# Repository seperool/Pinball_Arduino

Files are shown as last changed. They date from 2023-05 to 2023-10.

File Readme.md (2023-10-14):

# 1 OBJETIVO

## 1.1 Projeto Pinball

Desenvolver um brinquedo simples para crianças com transtorno de especto
autista (TEA) que envolva circuitos elétricos.  
O projeto é um pinball, de dimensões portatil (um pouco maior que uma
caixa de sapatos), construido com *Arduino UNO R3*, seis *LEDs* e seis
sensores que mapeiam a movimentação da bola. Com base no mapeamento da
movimentação da bola, em pontos predeterminados, os pontos do jogo são
marcados e contados, ou a partida é reiniciada e os pontos são zerados.
Como pode ser observado um exemplo desse modelo de pinball na figura .  

<figure>
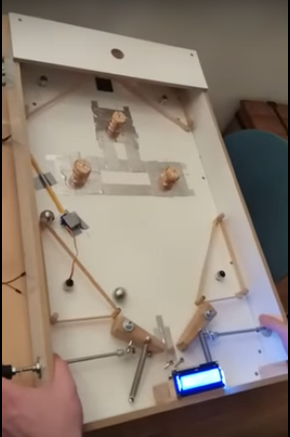
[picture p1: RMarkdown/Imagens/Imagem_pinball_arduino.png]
Exemplo pinball construido a partir de Arduino

<figcaption aria-hidden="true">Exemplo pinball construido a partir de
Arduino </figcaption>
</figure>

# 2 METODOLOGIA

## 2.1 Programação

    //Bibliotecas
    #include <LiquidCrystal.h>

    //Definindo os pinos que serão utilizados para ligação ao display LCD
    LiquidCrystal lcd(6, 7, 5, 4, 3, 2);

    //Definindo pinos dos LED
    int pinoLed_1 = 13; //Pino digital utilizado pelo LED 1 - Azul
    int pinoLed_2 = 12; //Pino digital utilizado pelo LED 2 - Verde
    int pinoLed_3 = 11; //Pino digital utilizado pelo LED 3 - Amarelo
    int pinoLed_4 = 10; //Pino digital utilizado pelo LED 4 - Vermelho
    int pinoLed_5 = 9; //Pino digital utilizado pelo LED 5 - Verde
    int pinoLed_6 = 8; //Pino digital utilizado pelo LED 6 - Azul

    // Cores LED e Pontos
    // Azul = LED 1 e 6 = 1 ponto
    // Verde = LED 2 e 5 = 2 ponto
    // Amarelo = LED 3 = 3 ponto
    // Vermelho = LED 4 = 0 ponto

    //Definindo pinos dos sensores óptico tcrt5000
    int pinoSensor_1 = 14; //Pino analogico A0 transformado em pino digital utilizado pelo sensor 1
    int pinoSensor_2 = 15; //Pino analogico A1 transformado em pino digital utilizado pelo sensor 2
    int pinoSensor_3 = 16; //Pino analogico A2 transformado em pino digital utilizado pelo sensor 3
    int pinoSensor_4 = 17; //Pino analogico A3 transformado em pino digital utilizado pelo sensor 4
    int pinoSensor_5 = 18; //Pino analogico A4 transformado em pino digital utilizado pelo sensor 5
    int pinoSensor_6 = 19; //Pino analogico A5 transformado em pino digital utilizado pelo sensor 6

    // Relação entre LED e sensores - Pinos
    // pinoSensor_1 -> pinoLed_1 - Pinos A0 e 13
    // pinoSensor_2 -> pinoLed_2 - Pinos A1 e 12
    // pinoSensor_3 -> pinoLed_3 - Pinos A2 e 11
    // pinoSensor_4 -> pinoLed_4 - Pinos A3 e 10
    // pinoSensor_5 -> pinoLed_5 - Pinos A4 e 9
    // pinoSensor_6 -> pinoLed_6 - Pinos A5 e 8

    // Variáveis
    int point = 0; //Contador de pontos
    int stop = 500; //Tempo de parada para o delay

    void setup() {
      //Define o número de colunas e linhas do LCD
      lcd.begin(16, 2);
      
      // Inicializando os Sensores
      pinMode(pinoSensor_1, INPUT); //Definindo o pino como entrada para o sensor 1
      pinMode(pinoSensor_2, INPUT); //Definindo o pino como entrada para o sensor 2
      pinMode(pinoSensor_3, INPUT); //Definindo o pino como entrada para o sensor 3
      pinMode(pinoSensor_4, INPUT); //Definindo o pino como entrada para o sensor 4
      pinMode(pinoSensor_5, INPUT); //Definindo o pino como entrada para o sensor 5
      pinMode(pinoSensor_6, INPUT); //Definindo o pino como entrada para o sensor 6

      // Inicializando os LED
      pinMode(pinoLed_1, OUTPUT); //Definindo o pino como saída para o LED 1 - Verde
      pinMode(pinoLed_2, OUTPUT); //Definindo o pino como saída para o LED 2 - Azul
      pinMode(pinoLed_3, OUTPUT); //Definindo o pino como saída para o LED 3 - Amarelo
      pinMode(pinoLed_4, OUTPUT); //Definindo o pino como saída para o LED 4 - Vermelho
      pinMode(pinoLed_5, OUTPUT); //Definindo o pino como saída para o LED 5 - Verde
      pinMode(pinoLed_6, OUTPUT); //Definindo o pino como saída para o LED 6 - Azul
      
      // Desligando os LED
      digitalWrite(pinoLed_1, LOW); //LED 1 inicia desligado
      digitalWrite(pinoLed_2, LOW); //LED 2 inicia desligado
      digitalWrite(pinoLed_3, LOW); //LED 3 inicia desligado
      digitalWrite(pinoLed_4, LOW); //LED 4 inicia desligado
      digitalWrite(pinoLed_5, LOW); //LED 5 inicia desligado
      digitalWrite(pinoLed_6, LOW); //LED 6 inicia desligado
    }

    void loop() {
      //Sensor
      if (digitalRead(pinoSensor_1) == LOW){ //Se a leitura do sensor 1 (Azul) for igual a LOW, faz
        digitalWrite(pinoLed_1, HIGH); //Acende o LED 1 - Azul
        point=point+1; //Adiciona 1 ponto
      }else if(digitalRead(pinoSensor_2) == LOW){ //Se a leitura do sensor 2 (Verde)) for igual a LOW, faz
        digitalWrite(pinoLed_2, HIGH); //Acende o LED 2 - Verde
        point=point+2; //Adiciona 2 ponto
      }else if(digitalRead(pinoSensor_3) == LOW){ //Se a leitura do sensor 3 (Amarelo) for igual a LOW, faz
        digitalWrite(pinoLed_3, HIGH); //Acende o LED 3 - Amarelo
        point=point+3; //Adiciona 3 ponto
      }else if(digitalRead(pinoSensor_5) == LOW){ //Se a leitura do sensor 5 (Verde) for igual a LOW, faz
        digitalWrite(pinoLed_5, HIGH); //Acende o LED 5 - Verde
        point=point+2; //Adiciona 2 ponto
      }else if(digitalRead(pinoSensor_6) == LOW){ //Se a leitura do sensor 6 (Azul) for igual a LOW, faz
        digitalWrite(pinoLed_6, HIGH); //Acende o LED 6 - Azul
        point=point+1; //Adiciona 1 ponto
      }else if(digitalRead(pinoSensor_4) == LOW){ //Se a leitura do sensor 4 (Vermelho) for igual a LOW, faz
        digitalWrite(pinoLed_4, HIGH); //Acende o LED 4 - Vermelho
        point=0; //Reinicia a contagem
      }
      
      //LCD
      //Limpa a tela
      lcd.clear();
      //Posiciona o cursor na coluna 1, linha 0;
      lcd.setCursor(1, 0);
      //Envia o texto entre aspas para o LCD
      lcd.print("Jogo Placar");
      //Posiciona o cursor na coluna 1, linha 1;
      lcd.setCursor(1, 1);
      //Imprime Contador de pontuação
      lcd.print(point);
      delay(stop);
      
      // Apagar LED
      digitalWrite(pinoLed_1, LOW); //Apaga o LED 1
      digitalWrite(pinoLed_2, LOW); //Apaga o LED 2
      digitalWrite(pinoLed_3, LOW); //Apaga o LED 3
      digitalWrite(pinoLed_4, LOW); //Apaga o LED 4
      digitalWrite(pinoLed_5, LOW); //Apaga o LED 5
      digitalWrite(pinoLed_6, LOW); //Apaga o LED 6
    }

## 2.2 Circuito

### 2.2.1 *Software* de desenho do circuito

Para os desenhos do circuito foi utilizado o software tipo *CAD*
[*Fritzing*](https://fritzing.org/), de codigo aberto, na versão beta. O
software oferece a possibilidade de desenhar tanto o modelo *breadboard*
quando o esquemático do circuito com arduino, sendo suas vantagens uma
biblioteca de dispositivos eletrônicos vasta, uma comunidade ativa para
tirar dúvidas e a criação de novos dispositivos eletrônicos.  

### 2.2.2 Breadboard

<figure>
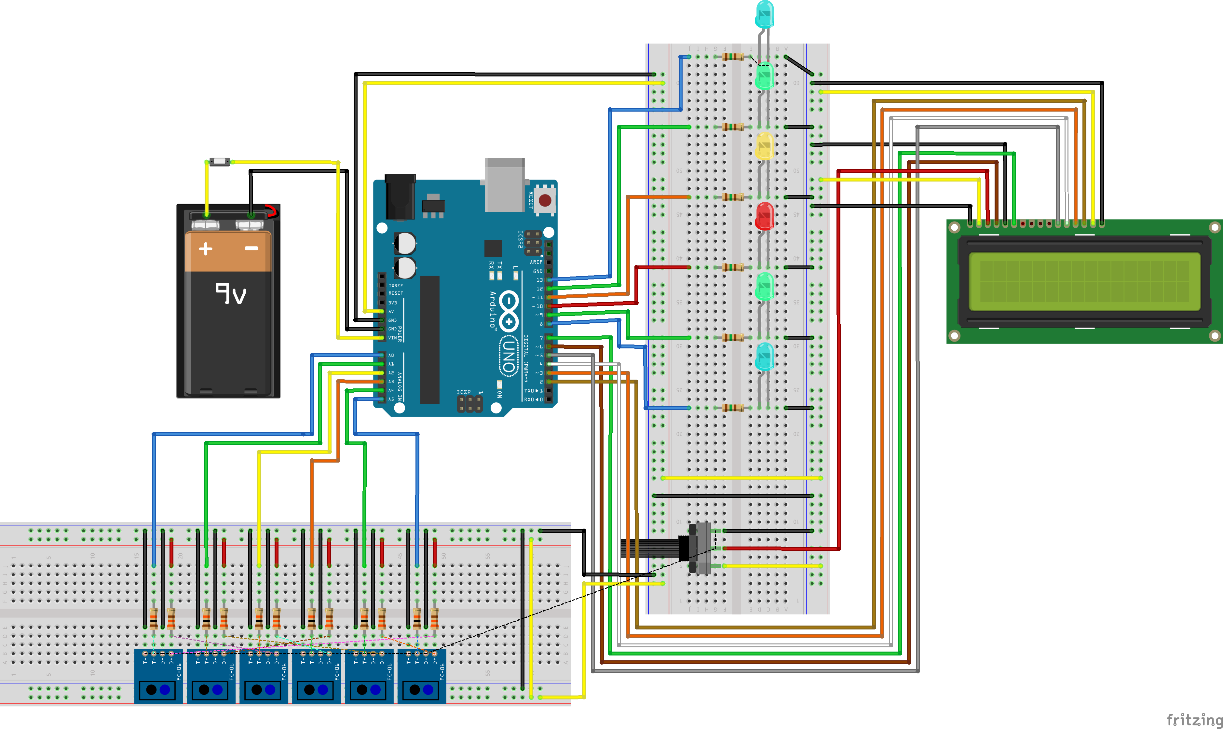
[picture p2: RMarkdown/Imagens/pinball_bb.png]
Circuito do Arduino com seis sensores ópticos, seis LEDs e um LCD.

<figcaption aria-hidden="true">Circuito do Arduino com seis sensores
ópticos, seis <em>LEDs</em> e um <em>LCD</em>. </figcaption>
</figure>

### 2.2.3 Diagrama esquemático

<figure>
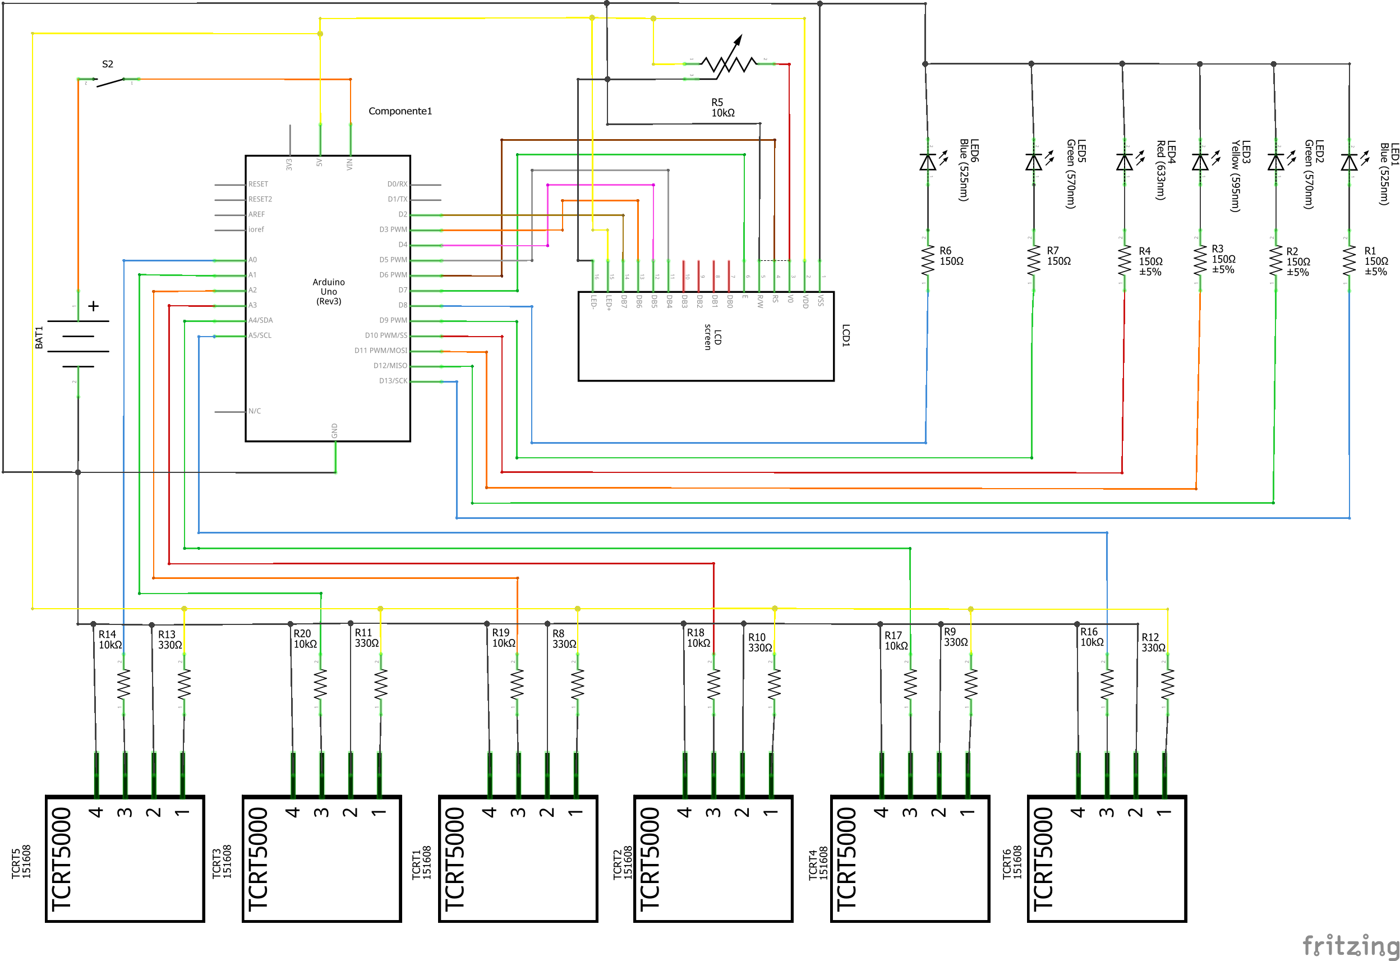
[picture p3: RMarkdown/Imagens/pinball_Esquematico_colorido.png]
Diagrama Esquemático do circuito do Arduino com seis sensores ópticos, seis LEDs e um LCD.

<figcaption aria-hidden="true">Diagrama Esquemático do circuito do
Arduino com seis sensores ópticos, seis <em>LEDs</em> e um
<em>LCD</em>.</figcaption>
</figure>

## 2.3 Modelagem estrutura

O desenho do Pinball foi desenvolvido com auxilio do *software*
[SolidWorks](https://www.solidworks.com/pt-br).  
O prototipo pode ser observado na figura .  

<figure>
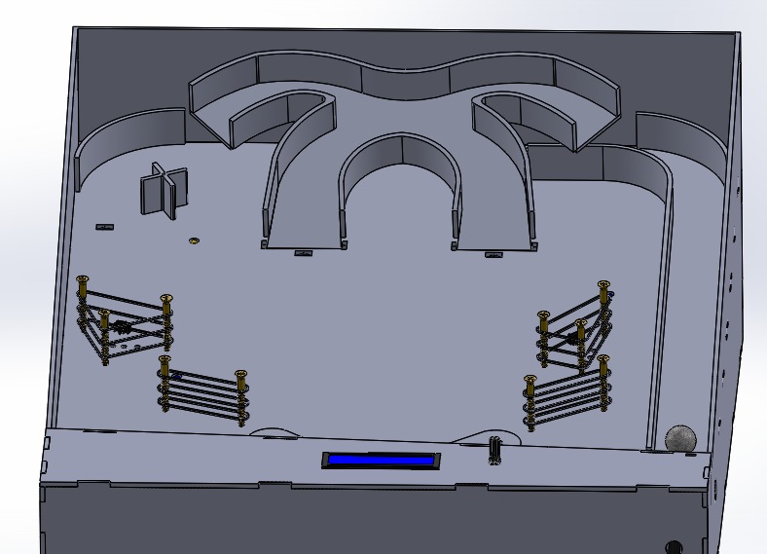
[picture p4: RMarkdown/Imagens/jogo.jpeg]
Pinball prototipo.

<figcaption aria-hidden="true">Pinball prototipo.</figcaption>
</figure>

Alguns detalhes como a rampa ficam evidenciadas na figura e o mecanismo
de lançamento da esfera na figura .  

<figure>
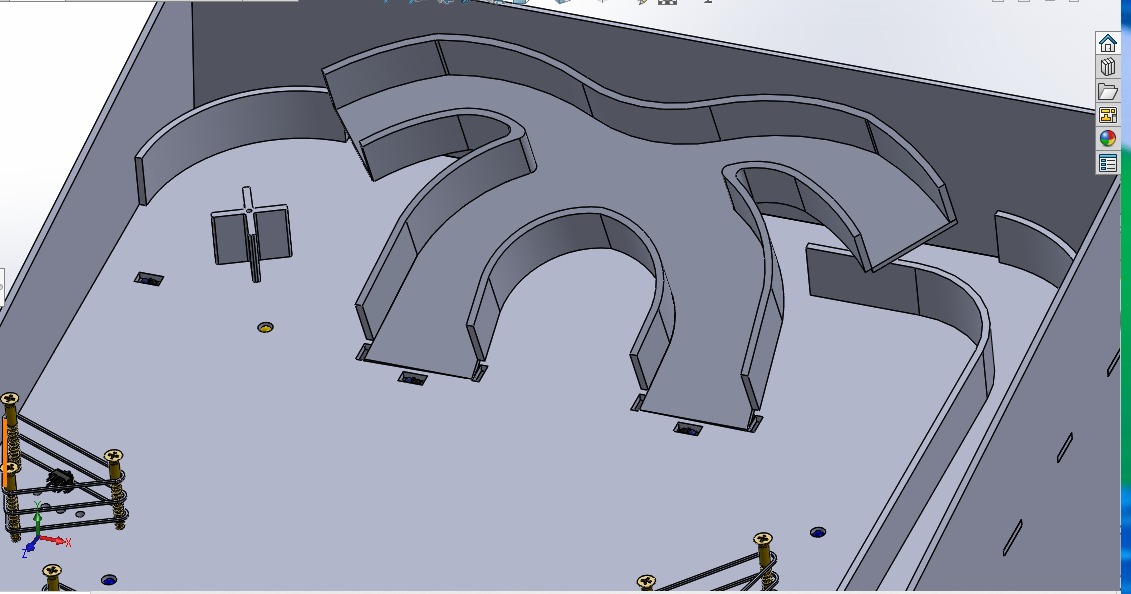
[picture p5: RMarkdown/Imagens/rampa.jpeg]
Detalhe da rampa.

<figcaption aria-hidden="true">Detalhe da rampa.</figcaption>
</figure>

<figure>
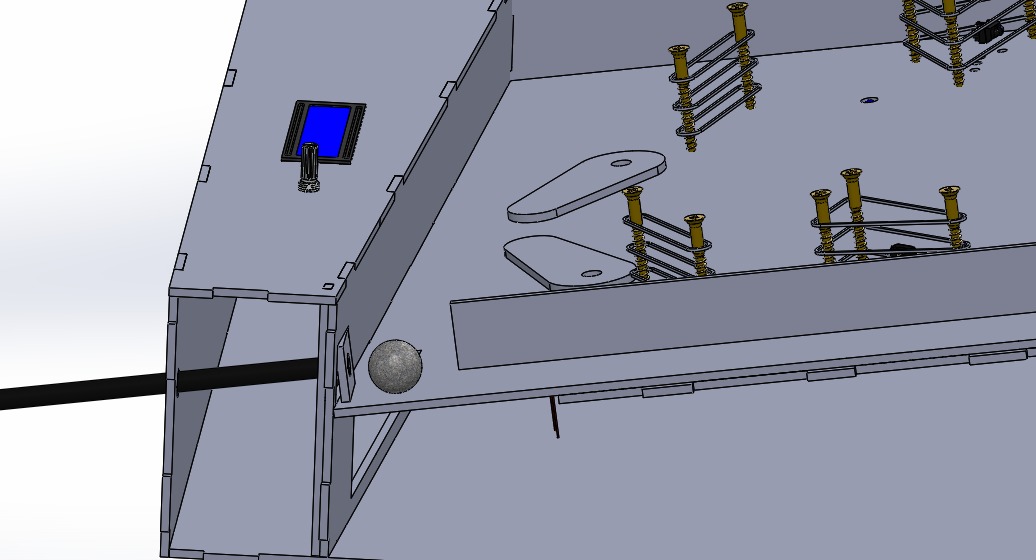
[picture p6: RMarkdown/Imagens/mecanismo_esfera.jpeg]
Mecanismo de lançamento da esfera.

<figcaption aria-hidden="true">Mecanismo de lançamento da
esfera.</figcaption>
</figure>

As vistas principais do Pinball nas figuras , e .  

<figure>
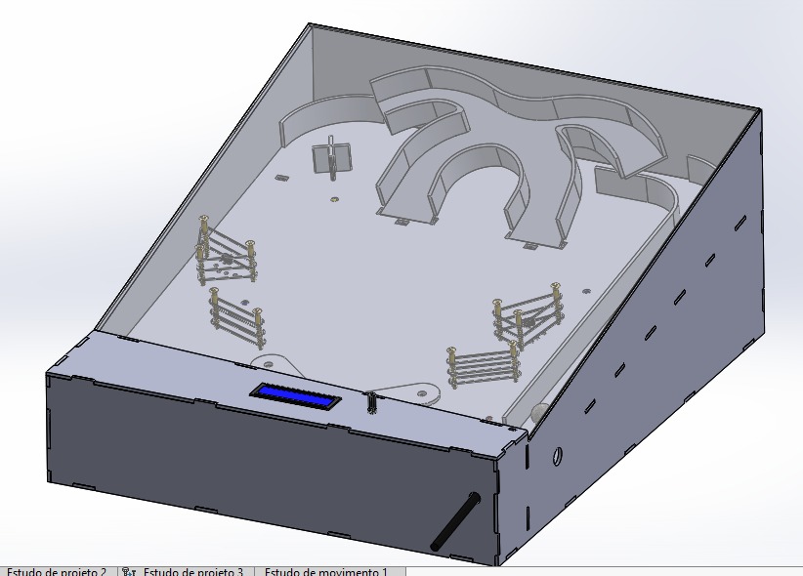
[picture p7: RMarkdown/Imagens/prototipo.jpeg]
Vista ortogonal.

<figcaption aria-hidden="true">Vista ortogonal.</figcaption>
</figure>

<figure>
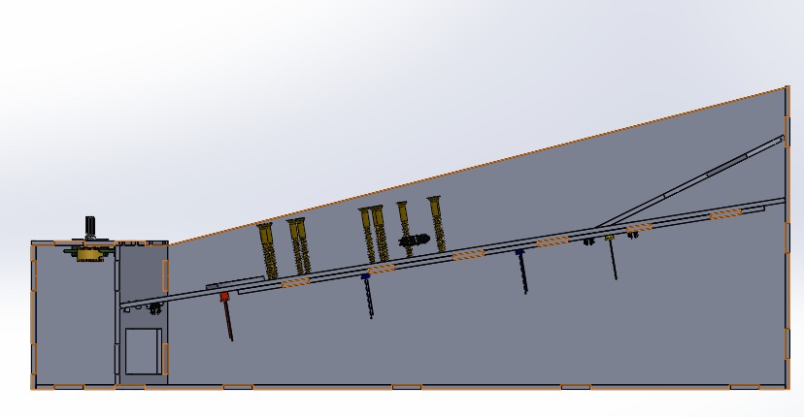
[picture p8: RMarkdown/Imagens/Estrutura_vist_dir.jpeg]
Vista da lateral direita.

<figcaption aria-hidden="true">Vista da lateral direita.</figcaption>
</figure>

<figure>
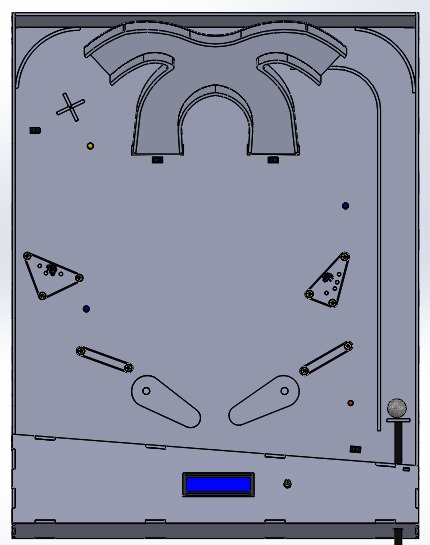
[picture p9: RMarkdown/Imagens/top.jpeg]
Vista superior.

<figcaption aria-hidden="true">Vista superior.</figcaption>
</figure>

## 2.4 Testes

Foram feitos dois testes do protótipo do circuito eletrônico:  
1. O primeiro para averiguar como seria o circuito na sua forma mais
simples, apenas o *Arduino UNO*, um sensor óptico, um *LED* e uma placa
de *LCD*, e a programação básica do Arduino para essa situação.  
Os principais fatores considerados foram:  
- A estrutura básica do circuito.  
- O funcionamento do *LCD*.  
- A programação básica implementada para unir esses componentes (sensor
óptico, *LED* e placa de *LCD*).  
2. O segundo experimento foi para ampliar o circuito, adicionando mais
cinco sensores ópticos e mais cinco *LEDs* (Figura ):  
- Averiguar a programação (como observada no Apêndice A).  
- Definir os pinos de cada componente eletrônico em relação ao *Arduino
UNO*.  
- A disposição e o sistema de cores definido para os *LEDs*,
relacionando os sensores e *LEDs*.  
- Transformação de pinos analógicos para digitais no *Arduino*, através
de programação, para comportar todos os componentes.  
- Testar da estrutura condicional (*if-else*) da programação.  
- O tempo ideal de *delay* para reconhecimento do objeto (bola de gude)
pelos sensores.  
- Definir e testar o sistema de pontuação do jogo.

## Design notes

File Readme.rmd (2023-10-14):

---
title: "Projeto Pinball"
subtitle: "Circuitos Elétricos 2"
author:
  - Franciellen Thurler Freire Allemão
  - Maria Clara Gonçalves de Almeida
  - Sergio Pedro Rodrigues Oliveira
date: "`r format(Sys.time(), '%d %B %Y')`"
committee:
  name: Paulo Victor de Souza Borges
  position: Orientador acadêmico
##lof: true
##lot: true
##toc-title: SUMÁRIO
output:
  md_document:
    number_sections: true
    variant: markdown_github
  pdf_document: 
    number_sections: true
    toc: FALSE
header-includes:
  - \usepackage{titling}
  - \pretitle{\begin{center}
    \includegraphics{./RMarkdown/azul.png}\LARGE\\}
  - \posttitle{\end{center}}
  - \renewcommand{\and}{\\}
bibliography: RMarkdown/Bibliografia_arduino.bib
csl: RMarkdown/abnt.csl
---

\thispagestyle{empty}

\newpage

\pagenumbering{roman}

```{=latex}
\setcounter{tocdepth}{4}
\renewcommand{\contentsname}{SUMÁRIO}
\tableofcontents
```

\newpage

```{=latex}
\setcounter{tocdepth}{4}
\renewcommand{\listfigurename}{LISTA DE FIGURAS}
\listoffigures
```

\newpage

```{=latex}
\setcounter{tocdepth}{4}
\renewcommand{\listtablename}{LISTA DE TABELAS}
\listoftables
```

```{r Pacotes, echo=FALSE, message=FALSE, warning=FALSE}
library(knitr)
```

\newpage

# OBJETIVO
## Projeto Pinball

Desenvolver um brinquedo simples para crianças com transtorno de especto autista (TEA) que envolva circuitos elétricos.\
O projeto é um pinball, de dimensões portatil (um pouco maior que uma caixa de sapatos), construido com *Arduino UNO R3*, seis *LEDs* e seis sensores que mapeiam a movimentação da bola. Com base no mapeamento da movimentação da bola, em pontos predeterminados, os pontos do jogo são marcados e contados, ou a partida é reiniciada e os pontos são zerados. Como pode ser observado um exemplo desse modelo de pinball na figura \ref{pinball_ex}.\

Exemplo pinball construido a partir de Arduino \label{pinball_ex}

\pagenumbering{arabic}
\newpage

# METODOLOGIA

## Programação

```
//Bibliotecas
#include <LiquidCrystal.h>

//Definindo os pinos que serão utilizados para ligação ao display LCD
LiquidCrystal lcd(6, 7, 5, 4, 3, 2);

//Definindo pinos dos LED
int pinoLed_1 = 13; //Pino digital utilizado pelo LED 1 - Azul
int pinoLed_2 = 12; //Pino digital utilizado pelo LED 2 - Verde
int pinoLed_3 = 11; //Pino digital utilizado pelo LED 3 - Amarelo
int pinoLed_4 = 10; //Pino digital utilizado pelo LED 4 - Vermelho
int pinoLed_5 = 9; //Pino digital utilizado pelo LED 5 - Verde
int pinoLed_6 = 8; //Pino digital utilizado pelo LED 6 - Azul

// Cores LED e Pontos
// Azul = LED 1 e 6 = 1 ponto
// Verde = LED 2 e 5 = 2 ponto
// Amarelo = LED 3 = 3 ponto
// Vermelho = LED 4 = 0 ponto

//Definindo pinos dos sensores óptico tcrt5000
int pinoSensor_1 = 14; //Pino analogico A0 transformado em pino digital utilizado pelo sensor 1
int pinoSensor_2 = 15; //Pino analogico A1 transformado em pino digital utilizado pelo sensor 2
int pinoSensor_3 = 16; //Pino analogico A2 transformado em pino digital utilizado pelo sensor 3
int pinoSensor_4 = 17; //Pino analogico A3 transformado em pino digital utilizado pelo sensor 4
int pinoSensor_5 = 18; //Pino analogico A4 transformado em pino digital utilizado pelo sensor 5
int pinoSensor_6 = 19; //Pino analogico A5 transformado em pino digital utilizado pelo sensor 6

// Relação entre LED e sensores - Pinos
// pinoSensor_1 -> pinoLed_1 - Pinos A0 e 13
// pinoSensor_2 -> pinoLed_2 - Pinos A1 e 12
// pinoSensor_3 -> pinoLed_3 - Pinos A2 e 11
// pinoSensor_4 -> pinoLed_4 - Pinos A3 e 10
// pinoSensor_5 -> pinoLed_5 - Pinos A4 e 9
// pinoSensor_6 -> pinoLed_6 - Pinos A5 e 8

// Variáveis
int point = 0; //Contador de pontos
int stop = 500; //Tempo de parada para o delay

void setup() {
  //Define o número de colunas e linhas do LCD
  lcd.begin(16, 2);
  
  // Inicializando os Sensores
  pinMode(pinoSensor_1, INPUT); //Definindo o pino como entrada para o sensor 1
  pinMode(pinoSensor_2, INPUT); //Definindo o pino como entrada para o sensor 2
  pinMode(pinoSensor_3, INPUT); //Definindo o pino como entrada para o sensor 3
  pinMode(pinoSensor_4, INPUT); //Definindo o pino como entrada para o sensor 4
  pinMode(pinoSensor_5, INPUT); //Definindo o pino como entrada para o sensor 5
  pinMode(pinoSensor_6, INPUT); //Definindo o pino como entrada para o sensor 6

  // Inicializando os LED
  pinMode(pinoLed_1, OUTPUT); //Definindo o pino como saída para o LED 1 - Verde
  pinMode(pinoLed_2, OUTPUT); //Definindo o pino como saída para o LED 2 - Azul
  pinMode(pinoLed_3, OUTPUT); //Definindo o pino como saída para o LED 3 - Amarelo
  pinMode(pinoLed_4, OUTPUT); //Definindo o pino como saída para o LED 4 - Vermelho
  pinMode(pinoLed_5, OUTPUT); //Definindo o pino como saída para o LED 5 - Verde
  pinMode(pinoLed_6, OUTPUT); //Definindo o pino como saída para o LED 6 - Azul
  
  // Desligando os LED
  digitalWrite(pinoLed_1, LOW); //LED 1 inicia desligado
  digitalWrite(pinoLed_2, LOW); //LED 2 inicia desligado
  digitalWrite(pinoLed_3, LOW); //LED 3 inicia desligado
  digitalWrite(pinoLed_4, LOW); //LED 4 inicia desligado
  digitalWrite(pinoLed_5, LOW); //LED 5 inicia desligado
  digitalWrite(pinoLed_6, LOW); //LED 6 inicia desligado
}

void loop() {
  //Sensor
  if (digitalRead(pinoSensor_1) == LOW){ //Se a leitura do sensor 1 (Azul) for igual a LOW, faz
    digitalWrite(pinoLed_1, HIGH); //Acende o LED 1 - Azul
    point=point+1; //Adiciona 1 ponto
  }else if(digitalRead(pinoSensor_2) == LOW){ //Se a leitura do sensor 2 (Verde)) for igual a LOW, faz
	digitalWrite(pinoLed_2, HIGH); //Acende o LED 2 - Verde
    point=point+2; //Adiciona 2 ponto
  }else if(digitalRead(pinoSensor_3) == LOW){ //Se a leitura do sensor 3 (Amarelo) for igual a LOW, faz
	digitalWrite(pinoLed_3, HIGH); //Acende o LED 3 - Amarelo
    point=point+3; //Adiciona 3 ponto
  }else if(digitalRead(pinoSensor_5) == LOW){ //Se a leitura do sensor 5 (Verde) for igual a LOW, faz
    digitalWrite(pinoLed_5, HIGH); //Acende o LED 5 - Verde
    point=point+2; //Adiciona 2 ponto
  }else if(digitalRead(pinoSensor_6) == LOW){ //Se a leitura do sensor 6 (Azul) for igual a LOW, faz
    digitalWrite(pinoLed_6, HIGH); //Acende o LED 6 - Azul
    point=point+1; //Adiciona 1 ponto
  }else if(digitalRead(pinoSensor_4) == LOW){ //Se a leitura do sensor 4 (Vermelho) for igual a LOW, faz
	digitalWrite(pinoLed_4, HIGH); //Acende o LED 4 - Vermelho
    point=0; //Reinicia a contagem
  }
  
  //LCD
  //Limpa a tela
  lcd.clear();
  //Posiciona o cursor na coluna 1, linha 0;
  lcd.setCursor(1, 0);
  //Envia o texto entre aspas para o LCD
  lcd.print("Jogo Placar");
  //Posiciona o cursor na coluna 1, linha 1;
  lcd.setCursor(1, 1);
  //Imprime Contador de pontuação
  lcd.print(point);
  delay(stop);
  
  // Apagar LED
  digitalWrite(pinoLed_1, LOW); //Apaga o LED 1
  digitalWrite(pinoLed_2, LOW); //Apaga o LED 2
  digitalWrite(pinoLed_3, LOW); //Apaga o LED 3
  digitalWrite(pinoLed_4, LOW); //Apaga o LED 4
  digitalWrite(pinoLed_5, LOW); //Apaga o LED 5
  digitalWrite(pinoLed_6, LOW); //Apaga o LED 6
}
```

## Circuito

### *Software* de desenho do circuito

Para os desenhos do circuito foi utilizado o software tipo *CAD* [*Fritzing*](https://fritzing.org/), de codigo aberto, na versão beta. O software oferece a possibilidade de desenhar tanto o modelo *breadboard* quando o esquemático do circuito com arduino, sendo suas vantagens uma biblioteca de dispositivos eletrônicos vasta, uma comunidade ativa para tirar dúvidas e a criação de novos dispositivos eletrônicos.\

### Breadboard

Circuito do Arduino com seis sensores ópticos, seis *LEDs* e um *LCD*. \label{circuito_bb}

\newpage

### Diagrama esquemático

Diagrama Esquemático do circuito do Arduino com seis sensores ópticos, seis *LEDs* e um *LCD*.

\newpage

## Modelagem estrutura
O desenho do Pinball foi desenvolvido com auxilio do *software* [SolidWorks](https://www.solidworks.com/pt-br).\
O prototipo pode ser observado na figura \ref{prototipo}.\

Pinball prototipo.\label{prototipo}

Alguns detalhes como a rampa ficam evidenciadas na figura \ref{rampa} e o mecanismo de lançamento da esfera na figura \ref{mecanismo_lançamento}.\

Detalhe da rampa.\label{rampa}

Mecanismo de lançamento da esfera.\label{mecanismo_lançamento}

As vistas principais do Pinball nas figuras \ref{est_ort}, \ref{est_dir} e \ref{est_top}.\

Vista ortogonal.\label{est_ort}

Vista da lateral direita.\label{est_dir}

Vista superior.\label{est_top}

\newpage

## Testes

Foram feitos dois testes do protótipo do circuito eletrônico:\
1. O primeiro para averiguar como seria o circuito na sua forma mais simples, apenas o *Arduino UNO*, um sensor óptico, um *LED* e uma placa de *LCD*, e a programação básica do Arduino para essa situação.\
Os principais fatores considerados foram:\
- A estrutura básica do circuito.\
- O funcionamento do *LCD*.\
- A programação básica implementada para unir esses componentes (sensor óptico, *LED* e placa de *LCD*).\
2. O segundo experimento foi para ampliar o circuito, adicionando mais cinco sensores ópticos e mais cinco *LEDs* (Figura \ref{circuito_bb}):\
- Averiguar a programação (como observada no Apêndice A).\
- Definir os pinos de cada componente eletrônico em relação ao *Arduino UNO*.\
- A disposição e o sistema de cores definido para os *LEDs*, relacionando os sensores e *LEDs*.\
- Transformação de pinos analógicos para digitais no *Arduino*, através de programação, para comportar todos os componentes.\
- Testar da estrutura condicional (*if-else*) da programação.\
- O tempo ideal de *delay* para reconhecimento do objeto (bola de gude) pelos sensores.\
- Definir e testar o sistema de pontuação do jogo.\

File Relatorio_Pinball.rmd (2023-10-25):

---
title: "Projeto Pinball"
subtitle: "Circuitos Elétricos 2"
author:
  - Franciellen Thurler Freire Allemão
  - Maria Clara Gonçalves de Almeida
  - Sergio Pedro Rodrigues Oliveira
date: "`r format(Sys.time(), '%d %B %Y')`"
committee:
  name: Paulo Victor de Souza Borges
  position: Orientador acadêmico
##lof: true
##lot: true
##toc-title: SUMÁRIO
output:
  odt_document: 
    number_sections: true
  md_document:
    number_sections: true
    variant: markdown_github
  html_document:
    number_sections: true
    df_print: paged
  github_document: 
  pdf_document: 
    number_sections: true
    toc: FALSE
  word_document: 
    toc: TRUE
    number_sections: true
header-includes:
  - \usepackage{titling}
  - \pretitle{\begin{center}
    \includegraphics{./RMarkdown/azul.png}\LARGE\\}
  - \posttitle{\end{center}}
  - \renewcommand{\and}{\\}
bibliography: RMarkdown/Bibliografia_arduino.bib
csl: RMarkdown/abnt.csl
---

\thispagestyle{empty}

\newpage

\pagenumbering{roman}

```{=latex}
\setcounter{tocdepth}{4}
\renewcommand{\contentsname}{SUMÁRIO}
\tableofcontents
```

\newpage

```{=latex}
\setcounter{tocdepth}{4}
\renewcommand{\listfigurename}{LISTA DE FIGURAS}
\listoffigures
```

\newpage

```{=latex}
\setcounter{tocdepth}{4}
\renewcommand{\listtablename}{LISTA DE TABELAS}
\listoftables
```

```{r Pacotes, echo=FALSE, message=FALSE, warning=FALSE}
library(knitr)
```

\newpage

# OBJETIVO
## Projeto Pinball

Desenvolver um brinquedo simples para crianças com transtorno de especto autista (TEA) que envolva circuitos elétricos.\
O projeto é um pinball, de dimensões portatil (um pouco maior que uma caixa de sapatos), construido com *Arduino UNO R3*, seis *LEDs* e seis sensores que mapeiam a movimentação da bola. Com base no mapeamento da movimentação da bola, em pontos predeterminados, os pontos do jogo são marcados e contados, ou a partida é reiniciada e os pontos são zerados. Como pode ser observado um exemplo desse modelo de pinball na figura \ref{pinball_ex}.\

Exemplo pinball construido a partir de Arduino \label{pinball_ex}

\pagenumbering{arabic}
\newpage

# LISTA DE MATERIAIS

```{r Lista_materiais, echo=FALSE, message=FALSE, warning=FALSE}
#data.frame
materiais <- c("Arduino UNO R3",
                  "Case para Arduino UNO",
                  "LED Difuso 5mm Vermelho",
                  "LED Difuso 5mm Amarelo",
                  "LED Difuso 5mm Azul",
                  "LED Difuso 5mm Verde",
                  "Resistor de 330 Ohm",
                  "Resistor de 150 Ohm",
                  "Resistor de 10k Ohm",
                  "Potenciometro 10k",
                  "Display LCD 16×2 Backlight Verde",
                  "Sensor Óptico Reflexivo TCRT5000",
                  "Cabos Jumper macho-macho",
                  "Tubo Termo Retrátil",
                  "Protoboard",
                  "Suporte Bateria 9V Plug P4",
                  "Bateria Recarregável 9v De Litio 680mah Rontek",
                  "Esfera De Aço Cromo 15mm",
                  "Chapa de MDF cru 3mm",
                  "Chapa de acrílico 2,4mm",
                  "Esfera De Aço Cromo 15mm - 10 Unit.",
                  "Parafuso francês 6mm.",
                  "Parafuso francês 10mm.",
                  "Porcas",
                  "Molas",
                  "Pistola de cola quente",
                  "Tubo de cola quente fino"
                  )
QDT <- c(1,1,1,1,2,2,6,6,6,1,1,6,1,1,2,1,1,1,1,1,1,1,2,7,4,1,2)
tbl_mat <- data.frame(materiais,QDT)

#Tabela
kable(tbl_mat, col.names = c("Materiais","Quantidade"), align = "lc", caption = "Lista de materiais")
```

\newpage

# DESENVOLVIMENTO

## O que é o *Arduino*?
O *Arduino* é uma pequena placa de microcontrolador. Contém diversos terminais que permitem a conexão com dispositivos externos. Os Arduinos podem ser energizados por um computador através de um plugue *USB*, por uma bateria 9V ou por uma fonte de alimentação. Eles podem ser programados pelo computador e, em seguida, desconectados, permitindo assim que trabalhem independentemente do computador.[@monk2013programaccao]\

A principal razão da necessidade de um computador é poder baixar programas para a placa de *Arduino*. Uma vez instalados nela, esses programas podem ser executados de forma independente.[@monk2015programaccao]\

A escolha da placa do *Arduino UNO R3*, entre as outras placas de *Arduino*, se dá por possuir um *layout* que fornece todas as entradas e saídas necessárias para o projeto, baixo custo e facilidade de obtenção (disponibilidade no mercado). O *layout* pode ser observado pela figura \ref{layout}. [@evans2013arduino]\

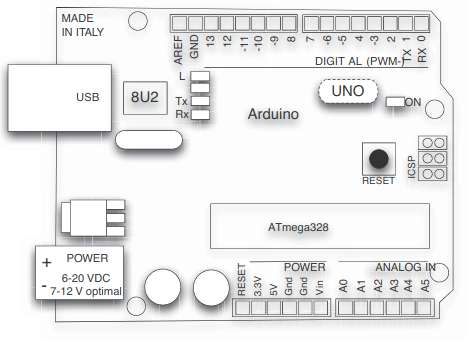
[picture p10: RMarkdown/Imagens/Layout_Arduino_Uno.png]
*Layout* da Placa do *Arduino UNO*. \label{layout}


\newpage

## Circuito

### *Software* de desenho do circuito

Para os desenhos do circuito foi utilizado o software tipo *CAD* [*Fritzing*](https://fritzing.org/), de codigo aberto, na versão beta. O software oferece a possibilidade de desenhar tanto o modelo *breadboard* quando o esquemático do circuito com arduino, sendo suas vantagens uma biblioteca de dispositivos eletrônicos vasta, uma comunidade ativa para tirar dúvidas e a criação de novos dispositivos eletrônicos.\

### Breadboard

Circuito do Arduino com seis sensores ópticos, seis *LEDs* e um *LCD*. \label{circuito_bb}

\newpage

### Diagrama esquemático

Diagrama Esquemático do circuito do Arduino com seis sensores ópticos, seis *LEDs* e um *LCD*.

\newpage

## Testes

Antes do projeto finalizado, foram feitos dois testes do protótipo do circuito eletrônico.\

1. O primeiro para averiguar como seria o circuito na sua forma mais simples, apenas o *Arduino UNO*, um sensor óptico, um *LED* e uma placa de *LCD*, e a programação básica do Arduino para essa situação.\
Os principais fatores considerados foram:\
- A estrutura básica do circuito.\
- O funcionamento do *LCD*.\
- A programação básica implementada para unir esses componentes (sensor óptico, *LED* e placa de *LCD*).\
2. O segundo experimento foi para ampliar o circuito, adicionando mais cinco sensores ópticos e mais cinco *LED*s (Figura \ref{circuito_bb}):\
- Averiguar a programação (como observada no Apêndice A).\
- Definir os pinos de cada componente eletrônico em relação ao *Arduino UNO*.\
- A disposição e o sistema de cores definido para os *LED*s, relacionando os sensores e *LED*s.\
- Transformação de pinos analógicos para digitais no *Arduino*, através de programação, para comportar todos os componentes.\
- Testar da estrutura condicional (*if-else*) da programação.\
- O tempo ideal de *delay* para reconhecimento do objeto (bola de gude) pelos sensores.\
- Definir e testar o sistema de pontuação do jogo.\

## Bateria

Sobre a escolha da bateria, o tipo de bateria que ofereceria um melhor desempenho para o projeto funcionar por varias horas e ainda sendo recarregavel é o modelo *Bateria Recarregável 9v De Litio 680mah Rontek* pelo preço de aproximadamente R$ [135,00](https://www.magazineluiza.com.br/bateria-recarregavel-9v-de-litio-680mah-rontek/p/jgfeg3d9a7/ea/rapo/), apresentando assim um alto custo. Foi escolhido para baratear o projeto a *bateria duracell alcalina 9v*, sendo esta mais usual, com bom desempenho, apesar de não ser recarregavele e ter por volta de 3 a 4 horas de vida utíl com o Pinball em funcionamento, pelo preço de aproximadamente R\$ [25,00](https://www.magazineluiza.com.br/bateria-duracell-alcalina-9v-preto-e-laranja-9v-1/p/dc3hca11h7/cj/batr/). Esta última serve aos propositos do projeto para demonstração.\

\newpage

## Desenho da estrutura

O desenho do Pinball foi desenvolvido com auxilio do *software* [SolidWorks](https://www.solidworks.com/pt-br).\
O prototipo pode ser observado na figura \ref{prototipo}.\

Pinball prototipo.\label{prototipo}

Alguns detalhes como a rampa ficam evidenciadas na figura \ref{rampa} e o mecanismo de lançamento da esfera na figura \ref{mecanismo_lançamento}.\

Detalhe da rampa.\label{rampa}

Mecanismo de lançamento da esfera.\label{mecanismo_lançamento}

As vistas principais do Pinball nas figuras \ref{est_ort}, \ref{est_dir} e \ref{est_top}.\

Vista ortogonal.\label{est_ort}

Vista da lateral direita.\label{est_dir}

Vista superior.\label{est_top}

\newpage

# MONTAGEM

## Montagem do circuito

- Com base nas medidas da estrutura do pinball foi possivel determinar a metragem de fios.\
- Na estrutura do pinball foram feitas aberturas para o encaixe dos dispostivos eletrônicos. (figura \ref{placa_est})\

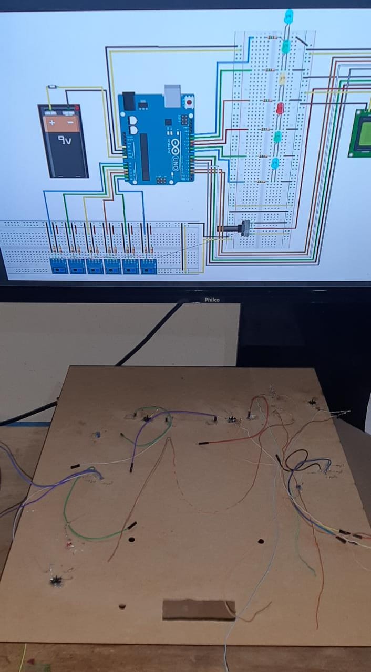
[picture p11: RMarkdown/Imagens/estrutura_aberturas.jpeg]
Placa da estrutura com furos para encaixe dos dispositivos. \label{placa_est}


- Os sensores, Arduino e placa de *LCD* foram presos a estrutura do pinball por cola quente. (Figura \ref{montagem_disp})\

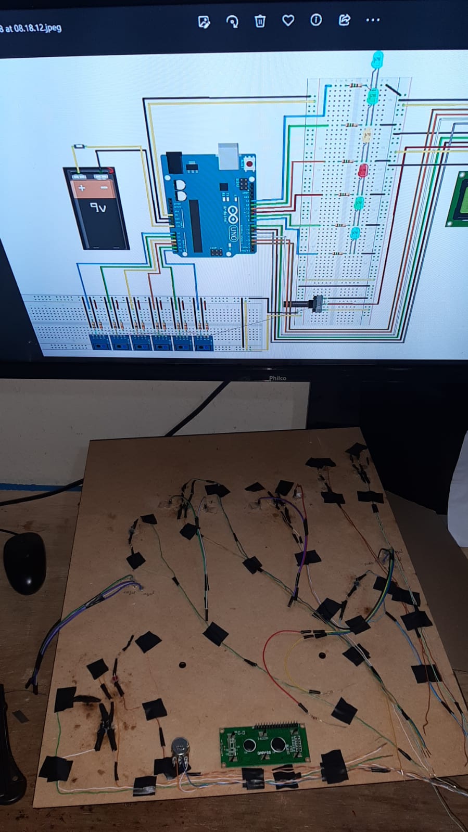
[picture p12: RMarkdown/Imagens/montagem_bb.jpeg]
Montagem dos dispositivos eletrônicos na estrutura do pinball. \label{montagem_disp}


\newpage

- Os fios e dispositivos eletrônicos foram soldados uns aos outros. (Figura \ref{fios})\

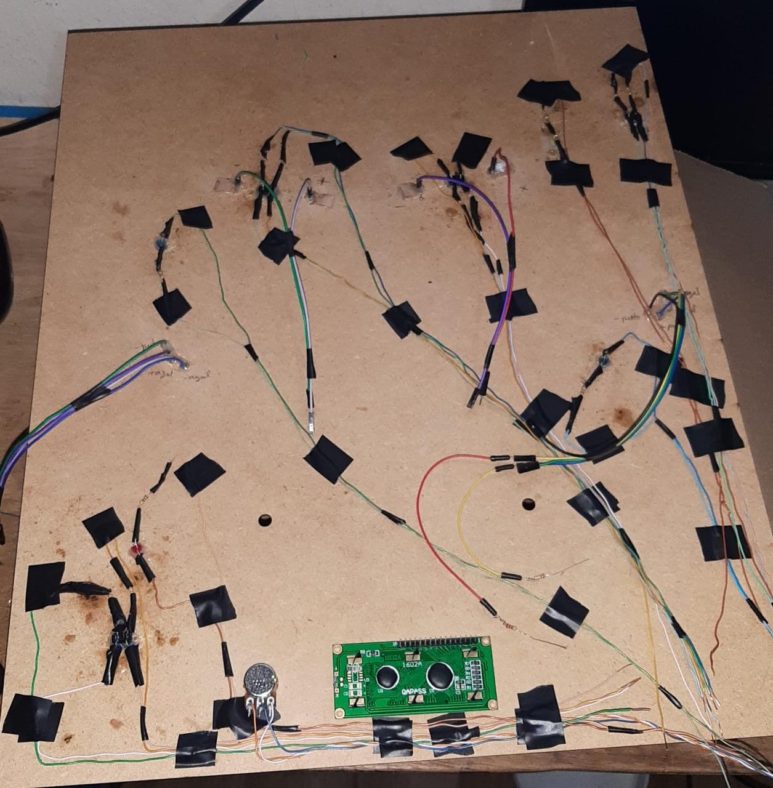
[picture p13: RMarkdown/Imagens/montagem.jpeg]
Fios soldados e presos na estrutura do pinball. \label{fios}


\newpage

## Montagem da estrutura

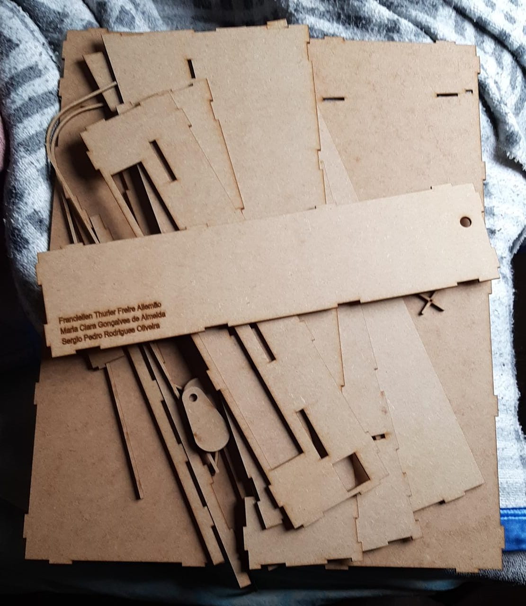
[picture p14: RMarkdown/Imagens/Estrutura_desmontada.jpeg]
Estrutura desmontada.\label{est_desmont}


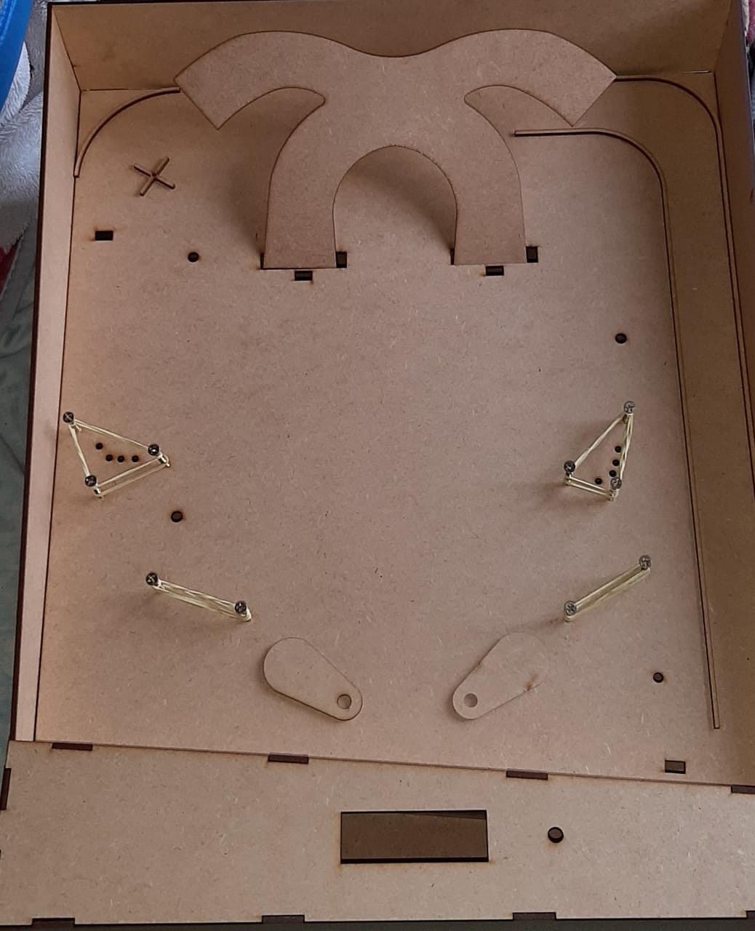
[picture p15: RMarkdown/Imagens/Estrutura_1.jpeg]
Estutura montada.\label{est_mont}


\newpage

# CONCLUSÃO

\newpage

# APÊNDICE A - PROGRAMAÇÃO
```
//Bibliotecas
#include <LiquidCrystal.h>

//Definindo os pinos que serão utilizados para ligação ao display LCD
LiquidCrystal lcd(6, 7, 5, 4, 3, 2);

//Definindo pinos dos LED
int pinoLed_1 = 13; //Pino digital utilizado pelo LED 1 - Azul
int pinoLed_2 = 12; //Pino digital utilizado pelo LED 2 - Verde
int pinoLed_3 = 11; //Pino digital utilizado pelo LED 3 - Amarelo
int pinoLed_4 = 10; //Pino digital utilizado pelo LED 4 - Vermelho
int pinoLed_5 = 9; //Pino digital utilizado pelo LED 5 - Verde
int pinoLed_6 = 8; //Pino digital utilizado pelo LED 6 - Azul

// Cores LED e Pontos
// Azul = LED 1 e 6 = 1 ponto
// Verde = LED 2 e 5 = 2 ponto
// Amarelo = LED 3 = 3 ponto
// Vermelho = LED 4 = 0 ponto

//Definindo pinos dos sensores óptico tcrt5000
int pinoSensor_1 = 14; //Pino analogico A0 transformado em pino digital utilizado pelo sensor 1
int pinoSensor_2 = 15; //Pino analogico A1 transformado em pino digital utilizado pelo sensor 2
int pinoSensor_3 = 16; //Pino analogico A2 transformado em pino digital utilizado pelo sensor 3
int pinoSensor_4 = 17; //Pino analogico A3 transformado em pino digital utilizado pelo sensor 4
int pinoSensor_5 = 18; //Pino analogico A4 transformado em pino digital utilizado pelo sensor 5
int pinoSensor_6 = 19; //Pino analogico A5 transformado em pino digital utilizado pelo sensor 6

// Relação entre LED e sensores - Pinos
// pinoSensor_1 -> pinoLed_1 - Pinos A0 e 13
// pinoSensor_2 -> pinoLed_2 - Pinos A1 e 12
// pinoSensor_3 -> pinoLed_3 - Pinos A2 e 11
// pinoSensor_4 -> pinoLed_4 - Pinos A3 e 10
// pinoSensor_5 -> pinoLed_5 - Pinos A4 e 9
// pinoSensor_6 -> pinoLed_6 - Pinos A5 e 8

// Variáveis
int point = 0; //Contador de pontos
int stop = 500; //Tempo de parada para o delay

void setup() {
  //Define o número de colunas e linhas do LCD
  lcd.begin(16, 2);
  
  // Inicializando os Sensores
  pinMode(pinoSensor_1, INPUT); //Definindo o pino como entrada para o sensor 1
  pinMode(pinoSensor_2, INPUT); //Definindo o pino como entrada para o sensor 2
  pinMode(pinoSensor_3, INPUT); //Definindo o pino como entrada para o sensor 3
  pinMode(pinoSensor_4, INPUT); //Definindo o pino como entrada para o sensor 4
  pinMode(pinoSensor_5, INPUT); //Definindo o pino como entrada para o sensor 5
  pinMode(pinoSensor_6, INPUT); //Definindo o pino como entrada para o sensor 6

  // Inicializando os LED
  pinMode(pinoLed_1, OUTPUT); //Definindo o pino como saída para o LED 1 - Verde
  pinMode(pinoLed_2, OUTPUT); //Definindo o pino como saída para o LED 2 - Azul
  pinMode(pinoLed_3, OUTPUT); //Definindo o pino como saída para o LED 3 - Amarelo
  pinMode(pinoLed_4, OUTPUT); //Definindo o pino como saída para o LED 4 - Vermelho
  pinMode(pinoLed_5, OUTPUT); //Definindo o pino como saída para o LED 5 - Verde
  pinMode(pinoLed_6, OUTPUT); //Definindo o pino como saída para o LED 6 - Azul
  
  // Desligando os LED
  digitalWrite(pinoLed_1, LOW); //LED 1 inicia desligado
  digitalWrite(pinoLed_2, LOW); //LED 2 inicia desligado
  digitalWrite(pinoLed_3, LOW); //LED 3 inicia desligado
  digitalWrite(pinoLed_4, LOW); //LED 4 inicia desligado
  digitalWrite(pinoLed_5, LOW); //LED 5 inicia desligado
  digitalWrite(pinoLed_6, LOW); //LED 6 inicia desligado
}

void loop() {
  //Sensor
  if (digitalRead(pinoSensor_1) == LOW){ //Se a leitura do sensor 1 (Azul) for igual a LOW, faz
    digitalWrite(pinoLed_1, HIGH); //Acende o LED 1 - Azul
    point=point+1; //Adiciona 1 ponto
  }else if(digitalRead(pinoSensor_2) == LOW){ //Se a leitura do sensor 2 (Verde)) for igual a LOW, faz
	digitalWrite(pinoLed_2, HIGH); //Acende o LED 2 - Verde
    point=point+2; //Adiciona 2 ponto
  }else if(digitalRead(pinoSensor_3) == LOW){ //Se a leitura do sensor 3 (Amarelo) for igual a LOW, faz
	digitalWrite(pinoLed_3, HIGH); //Acende o LED 3 - Amarelo
    point=point+3; //Adiciona 3 ponto
  }else if(digitalRead(pinoSensor_5) == LOW){ //Se a leitura do sensor 5 (Verde) for igual a LOW, faz
    digitalWrite(pinoLed_5, HIGH); //Acende o LED 5 - Verde
    point=point+2; //Adiciona 2 ponto
  }else if(digitalRead(pinoSensor_6) == LOW){ //Se a leitura do sensor 6 (Azul) for igual a LOW, faz
    digitalWrite(pinoLed_6, HIGH); //Acende o LED 6 - Azul
    point=point+1; //Adiciona 1 ponto
  }else if(digitalRead(pinoSensor_4) == LOW){ //Se a leitura do sensor 4 (Vermelho) for igual a LOW, faz
	digitalWrite(pinoLed_4, HIGH); //Acende o LED 4 - Vermelho
    point=0; //Reinicia a contagem
  }
  
  //LCD
  //Limpa a tela
  lcd.clear();
  //Posiciona o cursor na coluna 1, linha 0;
  lcd.setCursor(1, 0);
  //Envia o texto entre aspas para o LCD
  lcd.print("Jogo Placar");
  //Posiciona o cursor na coluna 1, linha 1;
  lcd.setCursor(1, 1);
  //Imprime Contador de pontuação
  lcd.print(point);
  delay(stop);
  
  // Apagar LED
  digitalWrite(pinoLed_1, LOW); //Apaga o LED 1
  digitalWrite(pinoLed_2, LOW); //Apaga o LED 2
  digitalWrite(pinoLed_3, LOW); //Apaga o LED 3
  digitalWrite(pinoLed_4, LOW); //Apaga o LED 4
  digitalWrite(pinoLed_5, LOW); //Apaga o LED 5
  digitalWrite(pinoLed_6, LOW); //Apaga o LED 6
}
```

\newpage

# BIBLIOGRAFIA

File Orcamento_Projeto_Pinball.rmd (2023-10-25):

---
title: "Orçamento Projeto Pinball"
subtitle: "Circuitos Elétricos 2"
author:
  - Franciellen Thurler Freire Allemão
  - Maria Clara Gonçalves de Almeida
  - Sergio Pedro Rodrigues Oliveira
date: "`r format(Sys.time(), '%d %B %Y')`"
committee:
  name: Paulo
  position: Orientador acadêmico
#lof: true
#lot: true
#toc-title: SUMÁRIO
output:
  odt_document: 
    number_sections: true
  word_document: 
    toc: TRUE
    number_sections: true
  github_document: 
  html_document:
    number_sections: true
    df_print: paged
  pdf_document: 
    number_sections: true
    toc: false
  md_document:
    number_sections: true
    variant: markdown_github
header-includes:
  - \usepackage{titling}
  - \pretitle{\begin{center}
    \includegraphics{./RMarkdown/azul.png}\LARGE\\}
  - \posttitle{\end{center}}
  - \renewcommand{\and}{\\}
bibliography: RMarkdown/Bibliografia_arduino.bib
csl: RMarkdown/abnt.csl
---

\thispagestyle{empty}

\newpage
\pagenumbering{roman}

```{=latex}
\setcounter{tocdepth}{4}
\renewcommand{\contentsname}{SUMÁRIO}
\tableofcontents
```

\newpage

```{=latex}
\setcounter{tocdepth}{4}
\renewcommand{\listfigurename}{LISTA DE FIGURAS}
\listoffigures
```

\newpage

```{=latex}
\setcounter{tocdepth}{4}
\renewcommand{\listtablename}{LISTA DE TABELAS}
\listoftables
```

```{r Pacotes, echo=FALSE, message=FALSE, warning=FALSE}
library(knitr)

```

\newpage

# PROJETO PINBALL
Desenvolver um brinquedo simples para crianças com transtorno de especto autista (TEA) que envolva circuitos elétricos.\
O projeto é um pinball, de dimensões portatil (um pouco maior que uma caixa de sapatos), construido com *Arduino UNO R3*, seis *LEDs* e seis sensores que mapeiam a movimentação da bola. Com base no mapeamento da movimentação da bola de gude, em pontos predeterminados, os pontos do jogo são marcados e contados, ou a partida é reiniciada e os pontos são zerados.\

Exemplo pinball construido a partir de Arduino

\pagenumbering{arabic} 
\newpage

# ORÇAMENTOS
## Orçamento da parte mecânica

```{r Orcamento_peças_mecânica, echo=FALSE, message=FALSE, warning=FALSE}
#data.frame
materiais_mec <- c("Esfera De Aço Cromo 15mm - 10 Unit.",
                   "Chapa de MDF cru 3mm",
                   "Chapa de acrílico 2,4mm",
                   "Parafuso francês 6mm.",
                   "Parafuso francês 10mm.",
                   "Porcas",
                   "Molas",
                   "Pistola de cola quente",
                   "Tubo de cola quente fino")
qtd_met_mec <- c(1,1,1,1,2,7,4,1,2)
preco_unit_met_mec <- c(25.81,32.45,70,3,3,1,3,38,4)
valor_total_mec <- qtd_met_mec*preco_unit_met_mec
orc_mec <- data.frame(materiais_mec,qtd_met_mec,preco_unit_met_mec,valor_total_mec)

#Tabela
kable(orc_mec,
      col.names = c("Peças Mecânicas", "Quantidade", "Preço unit.", "Valor Total"),
      align = "lccc",
      caption = "Orçamento dos peças mecânicas")
```

\newpage

## Orçamento dos dispositivos eletrônicos

```{r Orcamento_disp_eletronicos, echo=FALSE, message=FALSE, warning=FALSE}
#data.frame
materiais_elet <- c("Arduino UNO R3",
                  "Case para Arduino UNO",
                  "LED Difuso 5mm Vermelho",
                  "LED Difuso 5mm Amarelo",
                  "LED Difuso 5mm Azul",
                  "LED Difuso 5mm Verde",
                  "Resistor de 330 Ohm",
                  "Resistor de 150 Ohm",
                  "Resistor de 10k Ohm",
                  "Potenciometro 10k",
                  "Display LCD 16×2 Backlight Verde",
                  "Sensor Óptico Reflexivo TCRT5000",
                  "Cabos Jumper macho-macho",
                  "Kit Tubo Termo Retrátil 5 Cores",
                  "Protoboard",
                  "Suporte Bateria 9V Plug P4",
                  "bateria duracell alcalina 9v")
qtd_met_ele <- c(1,1,1,1,2,2,6,6,6,1,1,6,1,1,2,1,1)
preco_unit_met_ele <- c(90.15,18.90,0.23,0.23,0.47,0.47,0.18,0.18,0.05,2.28,20.80,1.21,9.40,32.10,16.05,13.20,24.50)
valor_total_disp <- qtd_met_ele*preco_unit_met_ele
orc_disp_ele <- data.frame(materiais_elet,qtd_met_ele,preco_unit_met_ele,valor_total_disp)

#Tabela
kable(orc_disp_ele,
      col.names = c("Dispositivos Eletrônicos", "Quantidade", "Preço unit.", "Valor Total"),
      align = "lccc",
      caption = "Orçamento dos dispositivos eletrônicos")
```

\newpage

# SITE DE FORNECEDORES

1. [Maker Hero](https://www.makerhero.com/)\
<https://www.makerhero.com/>

2. [Baú da Eletrônica](https://www.baudaeletronica.com.br/)\
<https://www.baudaeletronica.com.br/>

3. [Mercado livre - Esfera De Aço Cromo 15mm - 10 Unit.](https://produto.mercadolivre.com.br/MLB-752704314-esfera-de-aco-cromo-15mm-10-uni-_JM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)\
<https://produto.mercadolivre.com.br/MLB-752704314-esfera-de-aco-cromo-15mm-10-uni-_JM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>

\newpage

# RESUMO
- O preço orçado total dos materiais da parte mecânica (estrutura e mecanismos) dá em torno de R\$ `r sum(valor_total_mec)`.\
- O preço orçado total dos dispositivos eletônicos dá em torno de R\$ `r sum(valor_total_disp)`.\
- Valor total do projeto R$ `r sum(valor_total_disp)+sum(valor_total_mec)`.\

\newpage

# CONCLUSÃO

Apesar do preço orçado para o projeto (R$ `r sum(valor_total_disp)+sum(valor_total_mec)`), muito dos materiais eram de posse dos alunos. Sendo assim, já estavam disponíveis para o desenvolvimento do projeto sem a necessidade de compra, em sua maioria a parte dos dispositivos eletrônicos. O que barateou bastante o desenvolvimento.\
As dimensões das placas de MDF e acrílico foram orçadas com base nos desenhos da estrutura, desenvolvido em SolidWorks.\

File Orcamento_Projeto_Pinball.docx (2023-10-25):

# Orçamento Projeto Pinball

Circuitos Elétricos 2

Franciellen Thurler Freire Allemão

Maria Clara Gonçalves de Almeida

Sergio Pedro Rodrigues Oliveira

25 outubro 2023

# 1 PROJETO PINBALL

Desenvolver um brinquedo simples para crianças com transtorno de especto autista (TEA) que envolva circuitos elétricos.
O projeto é um pinball, de dimensões portatil (um pouco maior que uma caixa de sapatos), construido com Arduino UNO R3, seis LEDs e seis sensores que mapeiam a movimentação da bola. Com base no mapeamento da movimentação da bola de gude, em pontos predeterminados, os pontos do jogo são marcados e contados, ou a partida é reiniciada e os pontos são zerados.


Exemplo pinball construido a partir de Arduino

# 2 ORÇAMENTOS

## 2.1 Orçamento da parte mecânica

Orçamento dos peças mecânicas

Peças Mecânicas | Quantidade | Preço unit. | Valor Total
Esfera De Aço Cromo 15mm - 10 Unit. | 1 | 25.81 | 25.81
Chapa de MDF cru 3mm | 1 | 32.45 | 32.45
Chapa de acrílico 2,4mm | 1 | 70.00 | 70.00
Parafuso francês 6mm. | 1 | 3.00 | 3.00
Parafuso francês 10mm. | 2 | 3.00 | 6.00
Porcas | 7 | 1.00 | 7.00
Molas | 4 | 3.00 | 12.00
Pistola de cola quente | 1 | 38.00 | 38.00
Tubo de cola quente fino | 2 | 4.00 | 8.00

## 2.2 Orçamento dos dispositivos eletrônicos

Orçamento dos dispositivos eletrônicos

Dispositivos Eletrônicos | Quantidade | Preço unit. | Valor Total
Arduino UNO R3 | 1 | 90.15 | 90.15
Case para Arduino UNO | 1 | 18.90 | 18.90
LED Difuso 5mm Vermelho | 1 | 0.23 | 0.23
LED Difuso 5mm Amarelo | 1 | 0.23 | 0.23
LED Difuso 5mm Azul | 2 | 0.47 | 0.94
LED Difuso 5mm Verde | 2 | 0.47 | 0.94
Resistor de 330 Ohm | 6 | 0.18 | 1.08
Resistor de 150 Ohm | 6 | 0.18 | 1.08
Resistor de 10k Ohm | 6 | 0.05 | 0.30
Potenciometro 10k | 1 | 2.28 | 2.28
Display LCD 16×2 Backlight Verde | 1 | 20.80 | 20.80
Sensor Óptico Reflexivo TCRT5000 | 6 | 1.21 | 7.26
Cabos Jumper macho-macho | 1 | 9.40 | 9.40
Kit Tubo Termo Retrátil 5 Cores | 1 | 32.10 | 32.10
Protoboard | 2 | 16.05 | 32.10
Suporte Bateria 9V Plug P4 | 1 | 13.20 | 13.20
bateria duracell alcalina 9v | 1 | 24.50 | 24.50

# 3 SITE DE FORNECEDORES

1. Maker Hero (https://www.makerhero.com/) https://www.makerhero.com/
2. Baú da Eletrônica (https://www.baudaeletronica.com.br/) https://www.baudaeletronica.com.br/
3. Mercado livre - Esfera De Aço Cromo 15mm - 10 Unit. (https://produto.mercadolivre.com.br/MLB-752704314-esfera-de-aco-cromo-15mm-10-uni-_JM) https://produto.mercadolivre.com.br/MLB-752704314-esfera-de-aco-cromo-15mm-10-uni-_JM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

# 4 RESUMO

- O preço orçado total dos materiais da parte mecânica (estrutura e mecanismos) dá em torno de R$ 202.26.
- O preço orçado total dos dispositivos eletônicos dá em torno de R$ 255.49.
- Valor total do projeto R$ 457.75.

# 5 CONCLUSÃO

Apesar do preço orçado para o projeto (R$ 457.75), muito dos materiais eram de posse dos alunos. Sendo assim, já estavam disponíveis para o desenvolvimento do projeto sem a necessidade de compra, em sua maioria a parte dos dispositivos eletrônicos. O que barateou bastante o desenvolvimento.
As dimensões das placas de MDF e acrílico foram orçadas com base nos desenhos da estrutura, desenvolvido em SolidWorks.

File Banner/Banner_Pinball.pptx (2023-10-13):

## Brinquedo Pinball para crianças

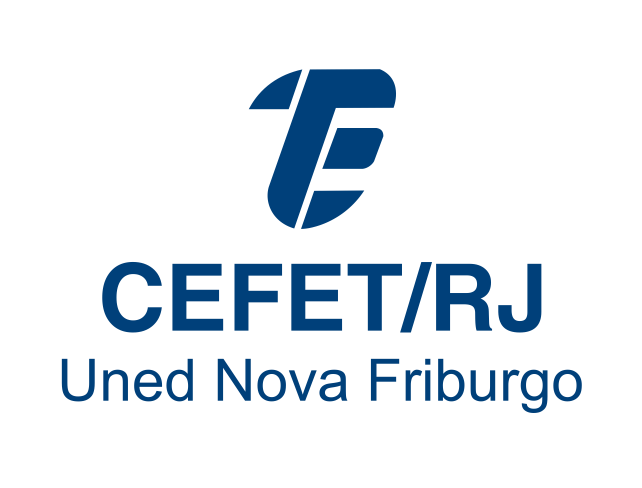
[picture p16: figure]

Franciellen Thurler Freire Allemão
Maria Clara Gonçalves de Almeida
Sergio Pedro Rodrigues Oliveira
Curso de Engenharia Elétrica – CEFET/RJ – Nova Friburgo

Paulo Victor de Souza Borges (Orientador)
CEFET/RJ – Nova Friburgo

Figura 2. Esquemático.


III. Modelagem

O software usado para projetar e modelar a estrutura do pinball foi o SolidWorks.

1. Introdução

O projeto é um pinball, de dimensões portátil (um pouco maior que uma caixa de sapatos), construído com Arduino UNO R3, seis LEDs e seis sensores ópticos que mapeiam a movimentação da bola. Com base no mapeamento da movimentação da bola, em lugares determinados, os pontos do jogo são marcados e contados, ou a partida é reiniciada e os pontos são zerados.

2. Objetivo

Desenvolver um brinquedo simples para crianças com transtorno de espectro autista (TEA) que envolva circuitos elétricos.

3. Metodologia

I. Programação

A programação usada no Arduino foi uma variante do C, um bloco de códigos chamado sketch.

Figura 4. Modelo vista superior.

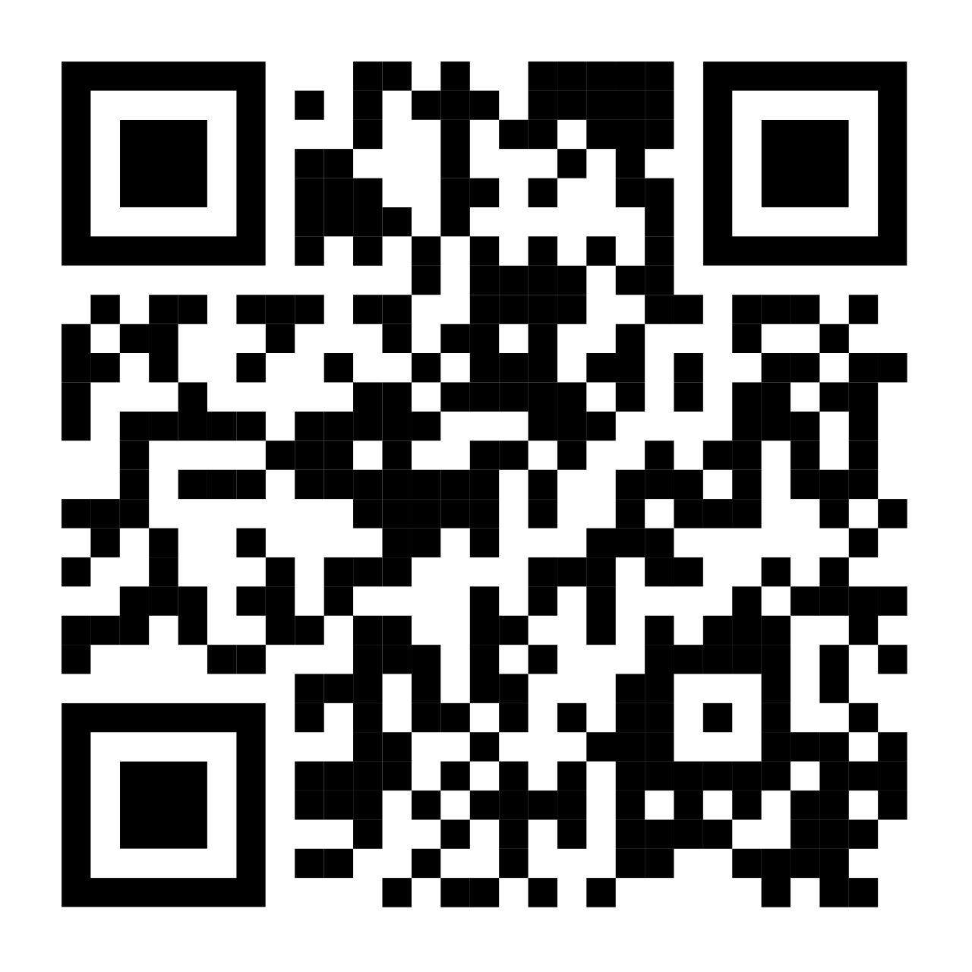
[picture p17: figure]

Figura 3. Modelo vista ortogonal.

4. Conclusão

Ao final dos testes o pinball se mostrou funcional, com o LCD contabilizando os pontos, os LEDs acendendo e a contagem reinicializando ao final do jogo.

O software Fritzing foi usado para projetar o circuito, o modelo breadboard usado para testes e o esquemático.

Figura 1. Modelo breadboard.

Modelo breadboard.

II. Circuito

5. Referências

EVANS, M.; NOBLE, J.; HOCHENBAUM, J. Arduino em Ação. [s.l.] Novatec Editora, 2013.
MONK, S. Programação com Arduino: começando com Sketches. [s.l.] Bookman Editora, 2013.
___. Programação com Arduino II: Passos avançados com sketches. [s.l.] Bookman Editora, 2015.

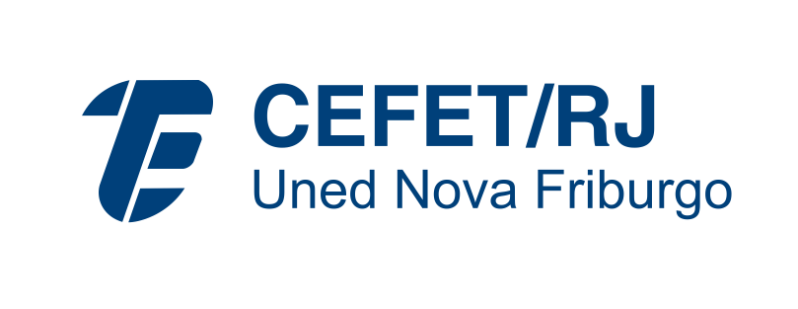
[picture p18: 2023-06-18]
RMarkdown/horiz_azul.png

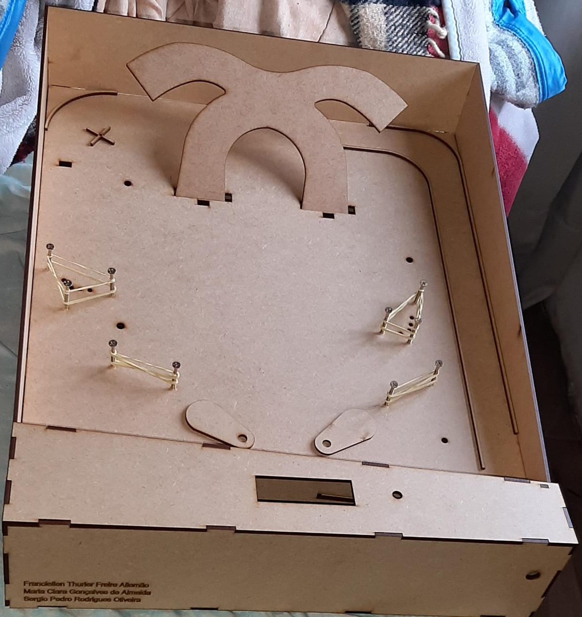
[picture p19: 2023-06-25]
RMarkdown/Imagens/Estrutura_2.jpeg

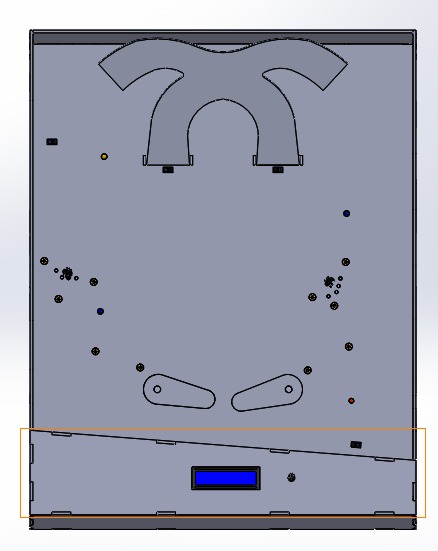
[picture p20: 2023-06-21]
RMarkdown/Imagens/Estrutura_vist_top.jpeg

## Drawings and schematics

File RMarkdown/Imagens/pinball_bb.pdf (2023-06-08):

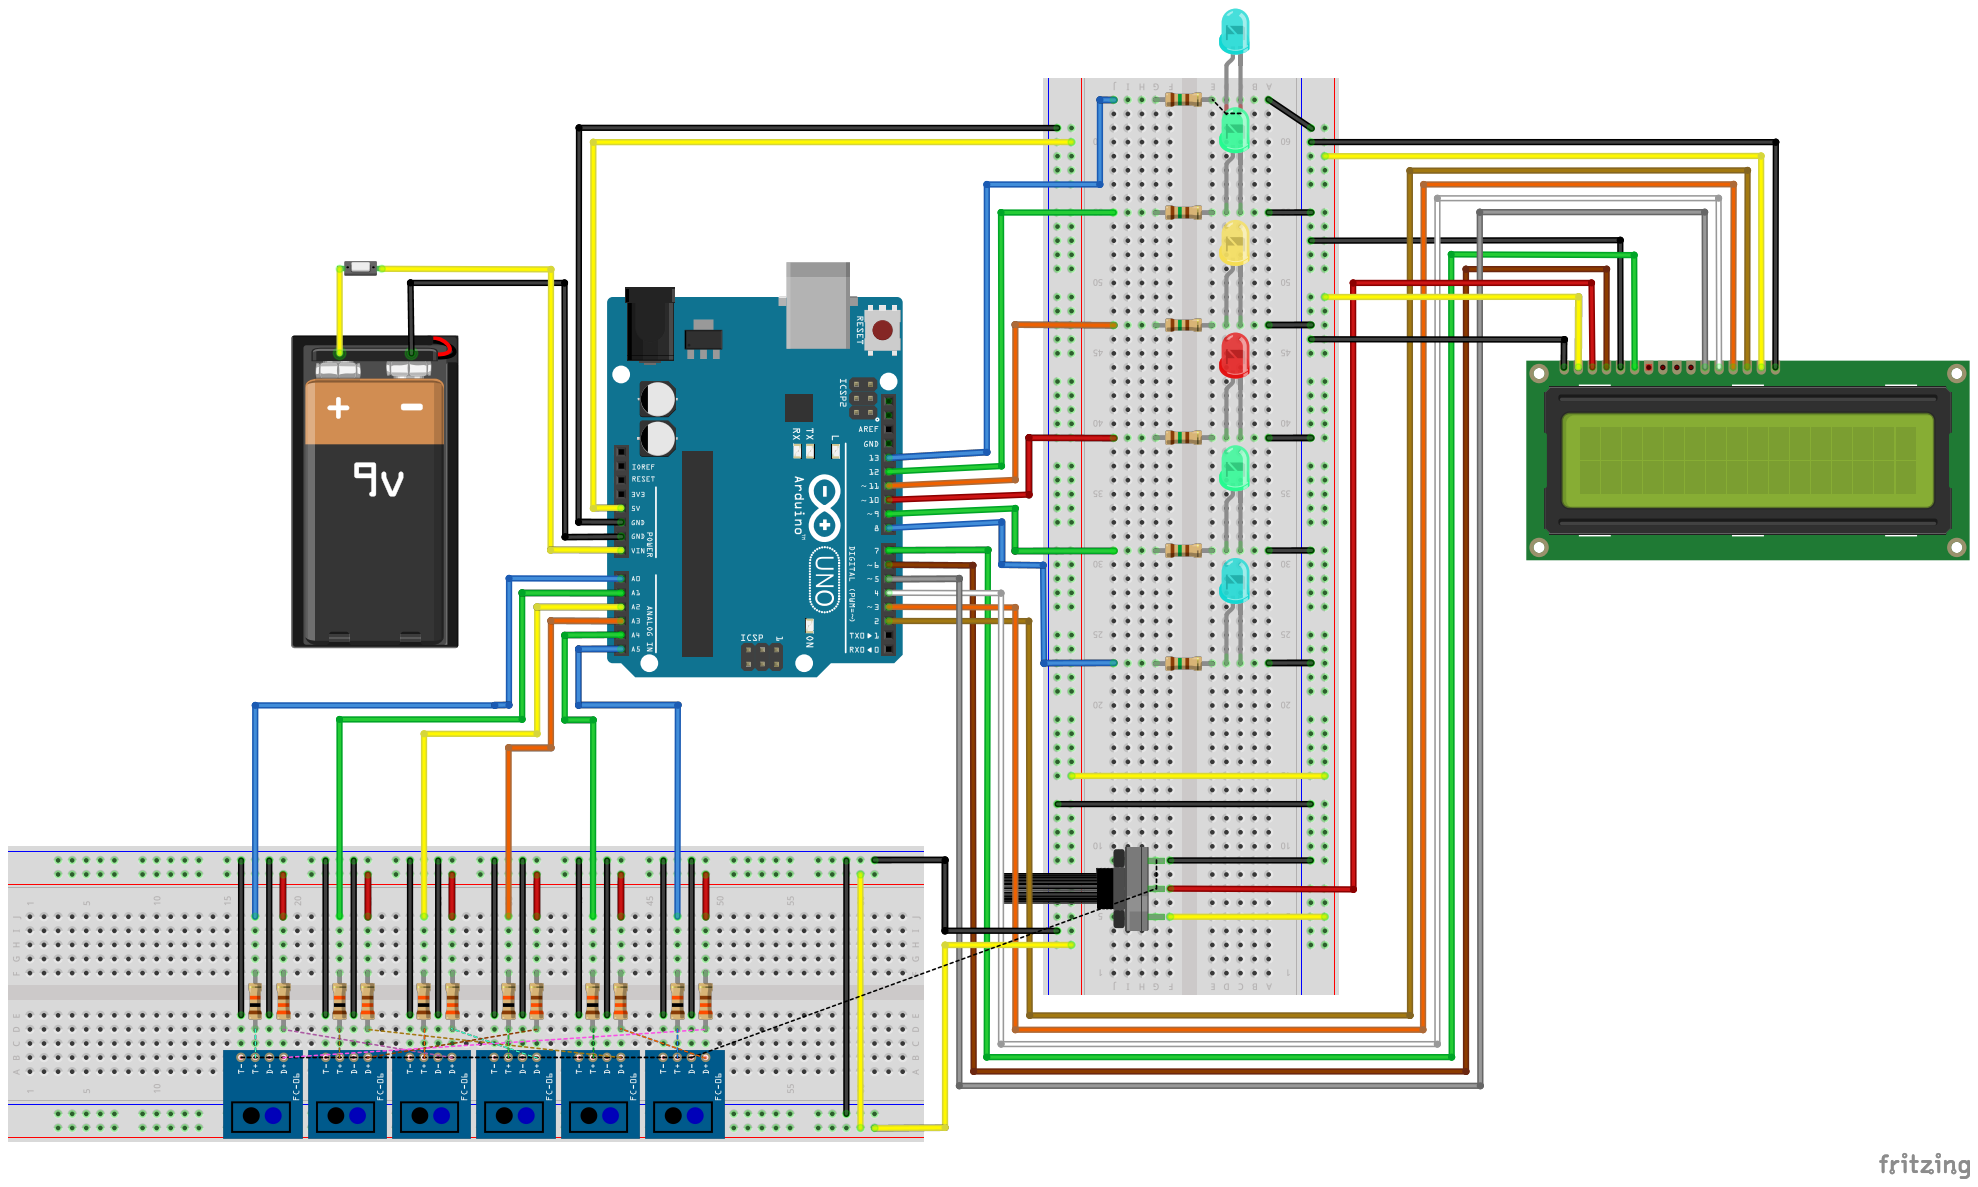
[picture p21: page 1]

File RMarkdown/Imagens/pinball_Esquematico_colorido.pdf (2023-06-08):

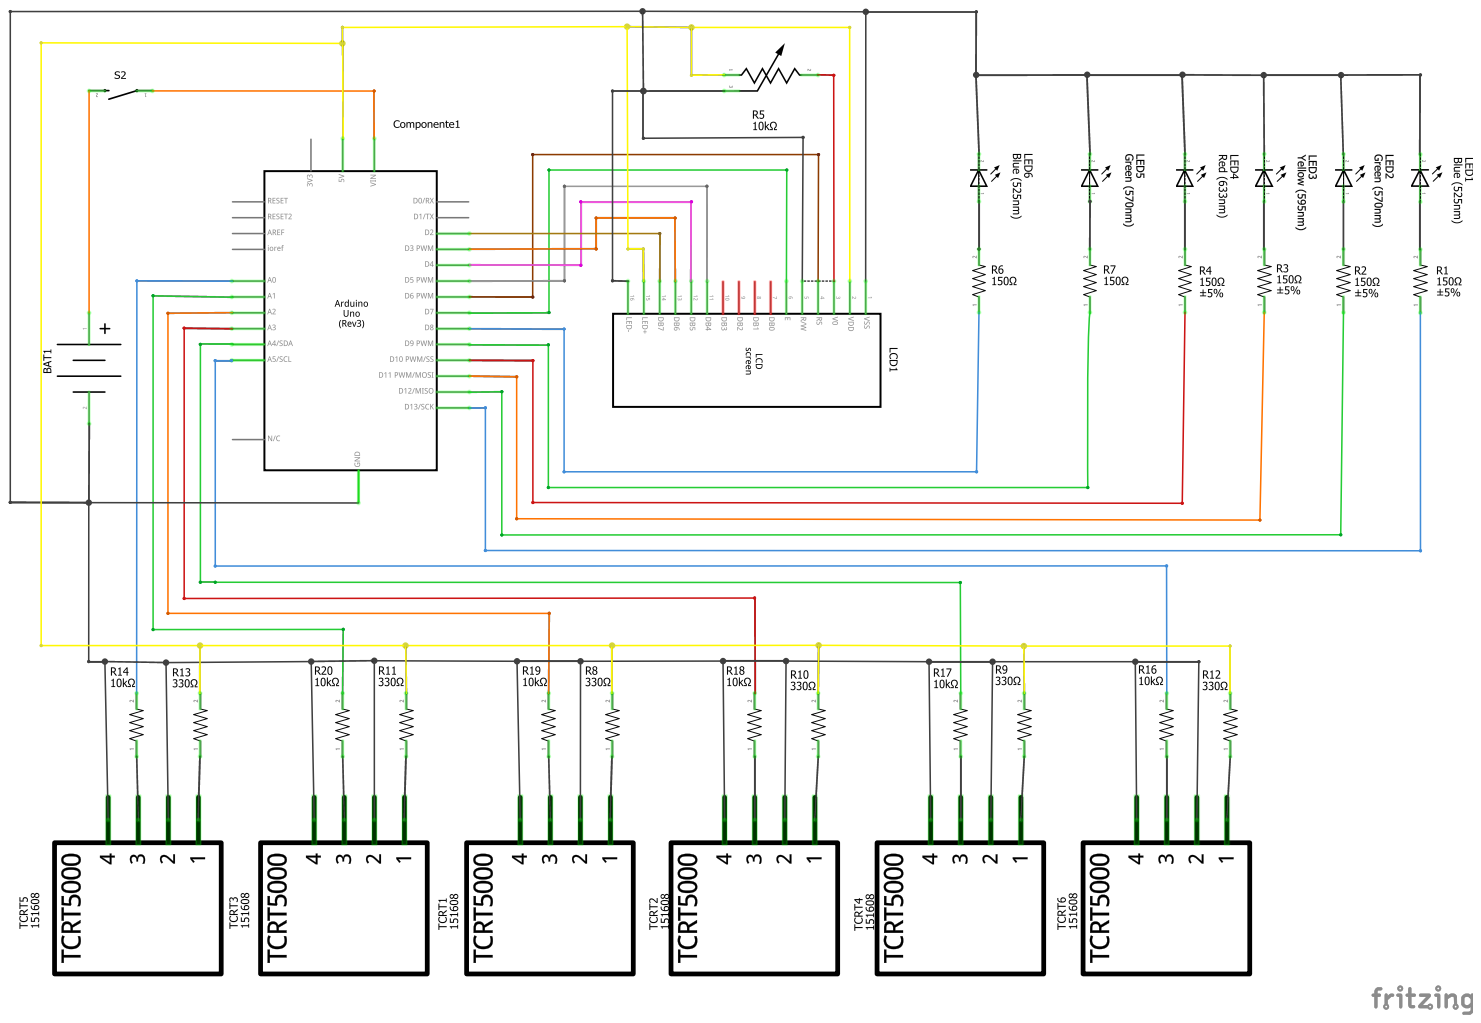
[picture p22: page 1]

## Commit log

2023-05-30 SKETCH Arduino
2023-06-01 Atualização mais dois LED e mais dois sensores
2023-06-04 Lista de materiais
2023-06-04 bibliografia arduino e soldagem
2023-06-05 Circuito do Arduino e atualização da programação
2023-06-05 Atualização programa Arduino
2023-06-05 Atualização programação Arduino
2023-06-05 Desenho circuito Arduino
2023-06-05 Programa Fritzing com circuito Arduino
    [Pinball.fzz]
2023-06-05 Desenho do circuito Arduino versão pdf
2023-06-07 Desenho do Circuito - Escolha do software
2023-06-08 Renovação de arquivos
    [Pinball.fzz]
2023-06-08 Imagens do Circuito
2023-06-08 Arquivos Fritzing
    [pinball.fzz]
2023-06-13 Numeração de paginas
2023-06-13 Numeração de paginas latex
2023-06-14 Imagem layout placa Arduino UNO
2023-06-17 Orçamento de materiais mecânicos
2023-06-19 Desenvolvimento - Arduino
2023-10-19 Reorganizando sensores
2023-10-25 Lista de materiais mecânicos
